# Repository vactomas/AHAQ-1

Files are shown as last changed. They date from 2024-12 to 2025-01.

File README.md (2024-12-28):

# AHAQ-1 -> AstroHex Air Quality v1

AHAQ-1 is an air quality station. Currently, it is an on-going project in development.

This device is based on the ESP32-C6 microcontroller. It features SCD4X CO2 sensor, BMP280 for temperature and ambient pressure measurements and SEN55 for PM1-10, NOx and VOCs. Additionaly, there are two I2C expansion ports for additional sensors. There is also a connector for E-Paper display.

ESPhome is the firmware of choice for AHAQ-1. This allows for easy integration with Home Assistant instances.

This repo contains all the necessary files to build and flash this device.

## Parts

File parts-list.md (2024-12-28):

# Part list

 - Linear regulator - https://www.tme.eu/cz/en/details/tlv75533pdbvr/ldo-unregulated-voltage-regulators/texas-instruments/
 - ESP32-C6-MINI - https://www.tme.eu/cz/en/details/esp32-c6-mini-1-n4/iot-wifi-bluetooth-modules/espressif/
 - SCD41
 - BMP280
 - SEN55 - https://www.tme.eu/cz/en/details/sen55-sdn-t/gas-sensors/sensirion/3-000-593/ - optional
 - E-Paper display - https://www.laskakit.cz/good-display-gdew0213t5d-2-13--250x122-epaper-displej-grayscale/ - optional
 - USB-C connector - https://www.tme.eu/cz/details/usb4105-gf-a/konektory-usb-a-ieee1394/gct/
 - ESD protection - https://www.tme.eu/cz/en/details/usblc6-4sc6y/protection-diodes-arrays/stmicroelectronics/
 - Crystal - https://www.tme.eu/cz/en/details/3cd-32.768kezb-t/smd-quartz-crystals/qst/qt3cd-32-768kezb-t/ - optional
 - FPC connector - https://www.tme.eu/cz/en/details/fh12-24s-0.5sh-55/connectors-ffc-fpc-0-5mm/hirose/fh12-24s-0-5sh-55/

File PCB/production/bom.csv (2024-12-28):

Designator | Footprint | Quantity | Value | LCSC Part #
C1, C12, C13, C2, C25, C26, C28, C29, C3, C30, C8 | 0603 | 11 | 100nF
C10, C11 | 0805 | 2 | 12pF
C14, C21, C22, C24, C6, C7 | 0805 | 6 | 4.7uF
C15, C16, C17, C18, C19, C20, C23, C27, C4, C5, C9 | 0603 | 11 | 1uF
D2, D3, D4 | D_SOD-123 | 3 | MBR0530
J1 | USB_C_Receptacle_GCT_USB4105-xx-A_16P_TopMnt_Horizontal | 1 | USB_C_Receptacle_USB2.0_16P
J2 | JST_SH_BM03B-SRSS-TB_1x03-1MP_P1.00mm_Vertical | 1 | UART
J3 | JST_SH_BM04B-SRSS-TB_1x04-1MP_P1.00mm_Vertical | 1 | I2C_3
J4 | JST_GH_BM06B-GHS-TBT_1x06-1MP_P1.25mm_Vertical | 1 | SEN55
J5 | JST_SH_BM04B-SRSS-TB_1x04-1MP_P1.00mm_Vertical | 1 | I2C_1
J6 | JST_SH_BM04B-SRSS-TB_1x04-1MP_P1.00mm_Vertical | 1 | I2C_2
J9 | Hirose_FH12-24S-0.5SH_1x24-1MP_P0.50mm_Horizontal | 1 | E-Paper
L1 | 0805 | 1 | 68uH
Q1 | SOT-323_SC-70 | 1 | Si1308EDL
R10 | 0402 | 1 | 10M
R11 | 0603 | 1 | 10K
R13 | 0805 | 1 | 0.47R
R14, R15 | 0603 | 2 | 2.2K
R5, R6 | 0603 | 2 | 5.1K
U1 | ESP32-C6-MINI-1 | 1 | ESP32-C6-MINI-1/U
U2 | Sensirion_SCD4x-1EP_10.1x10.1mm_P1.25mm_EP4.8x4.8mm | 1 | SCD41-D-R2
U3 | Bosch_LGA-8_2x2.5mm_P0.65mm_ClockwisePinNumbering | 1 | BMP280
U4, U5, U7 | SOT-23-5 | 3 | TLV75533PDBV
U6 | SOT-666 | 1 | USBLC6-2P6
Y1 | Crystal_SMD_3215-2Pin_3.2x1.5mm | 1 | 32.768kHz

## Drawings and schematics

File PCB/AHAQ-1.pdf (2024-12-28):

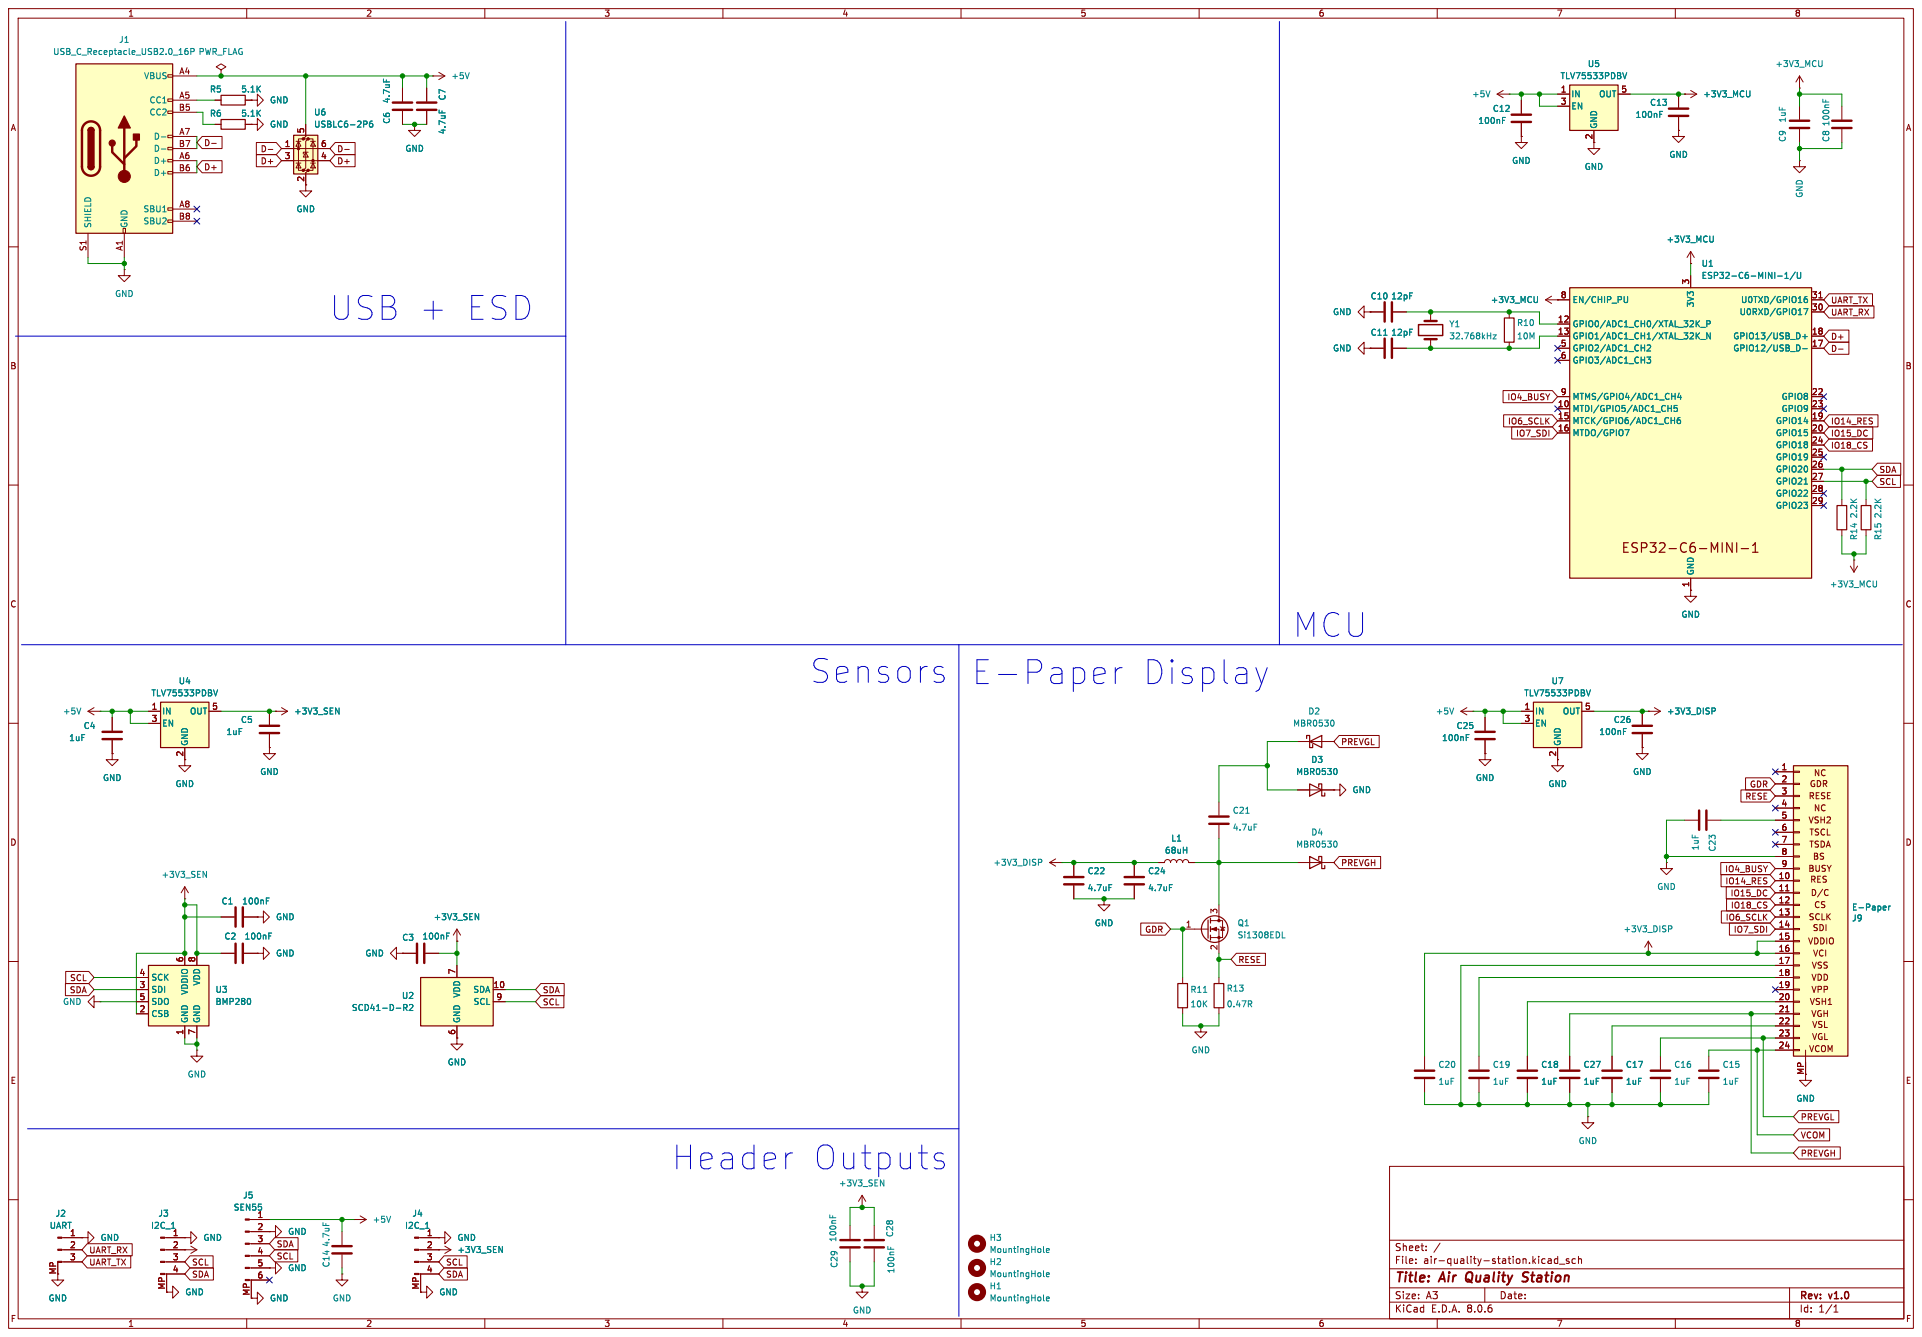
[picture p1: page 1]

1 CSB 2 SDI 3 SCK 4 SDO 5 VDDIO

Id: 1/1 Title: Air Quality Station

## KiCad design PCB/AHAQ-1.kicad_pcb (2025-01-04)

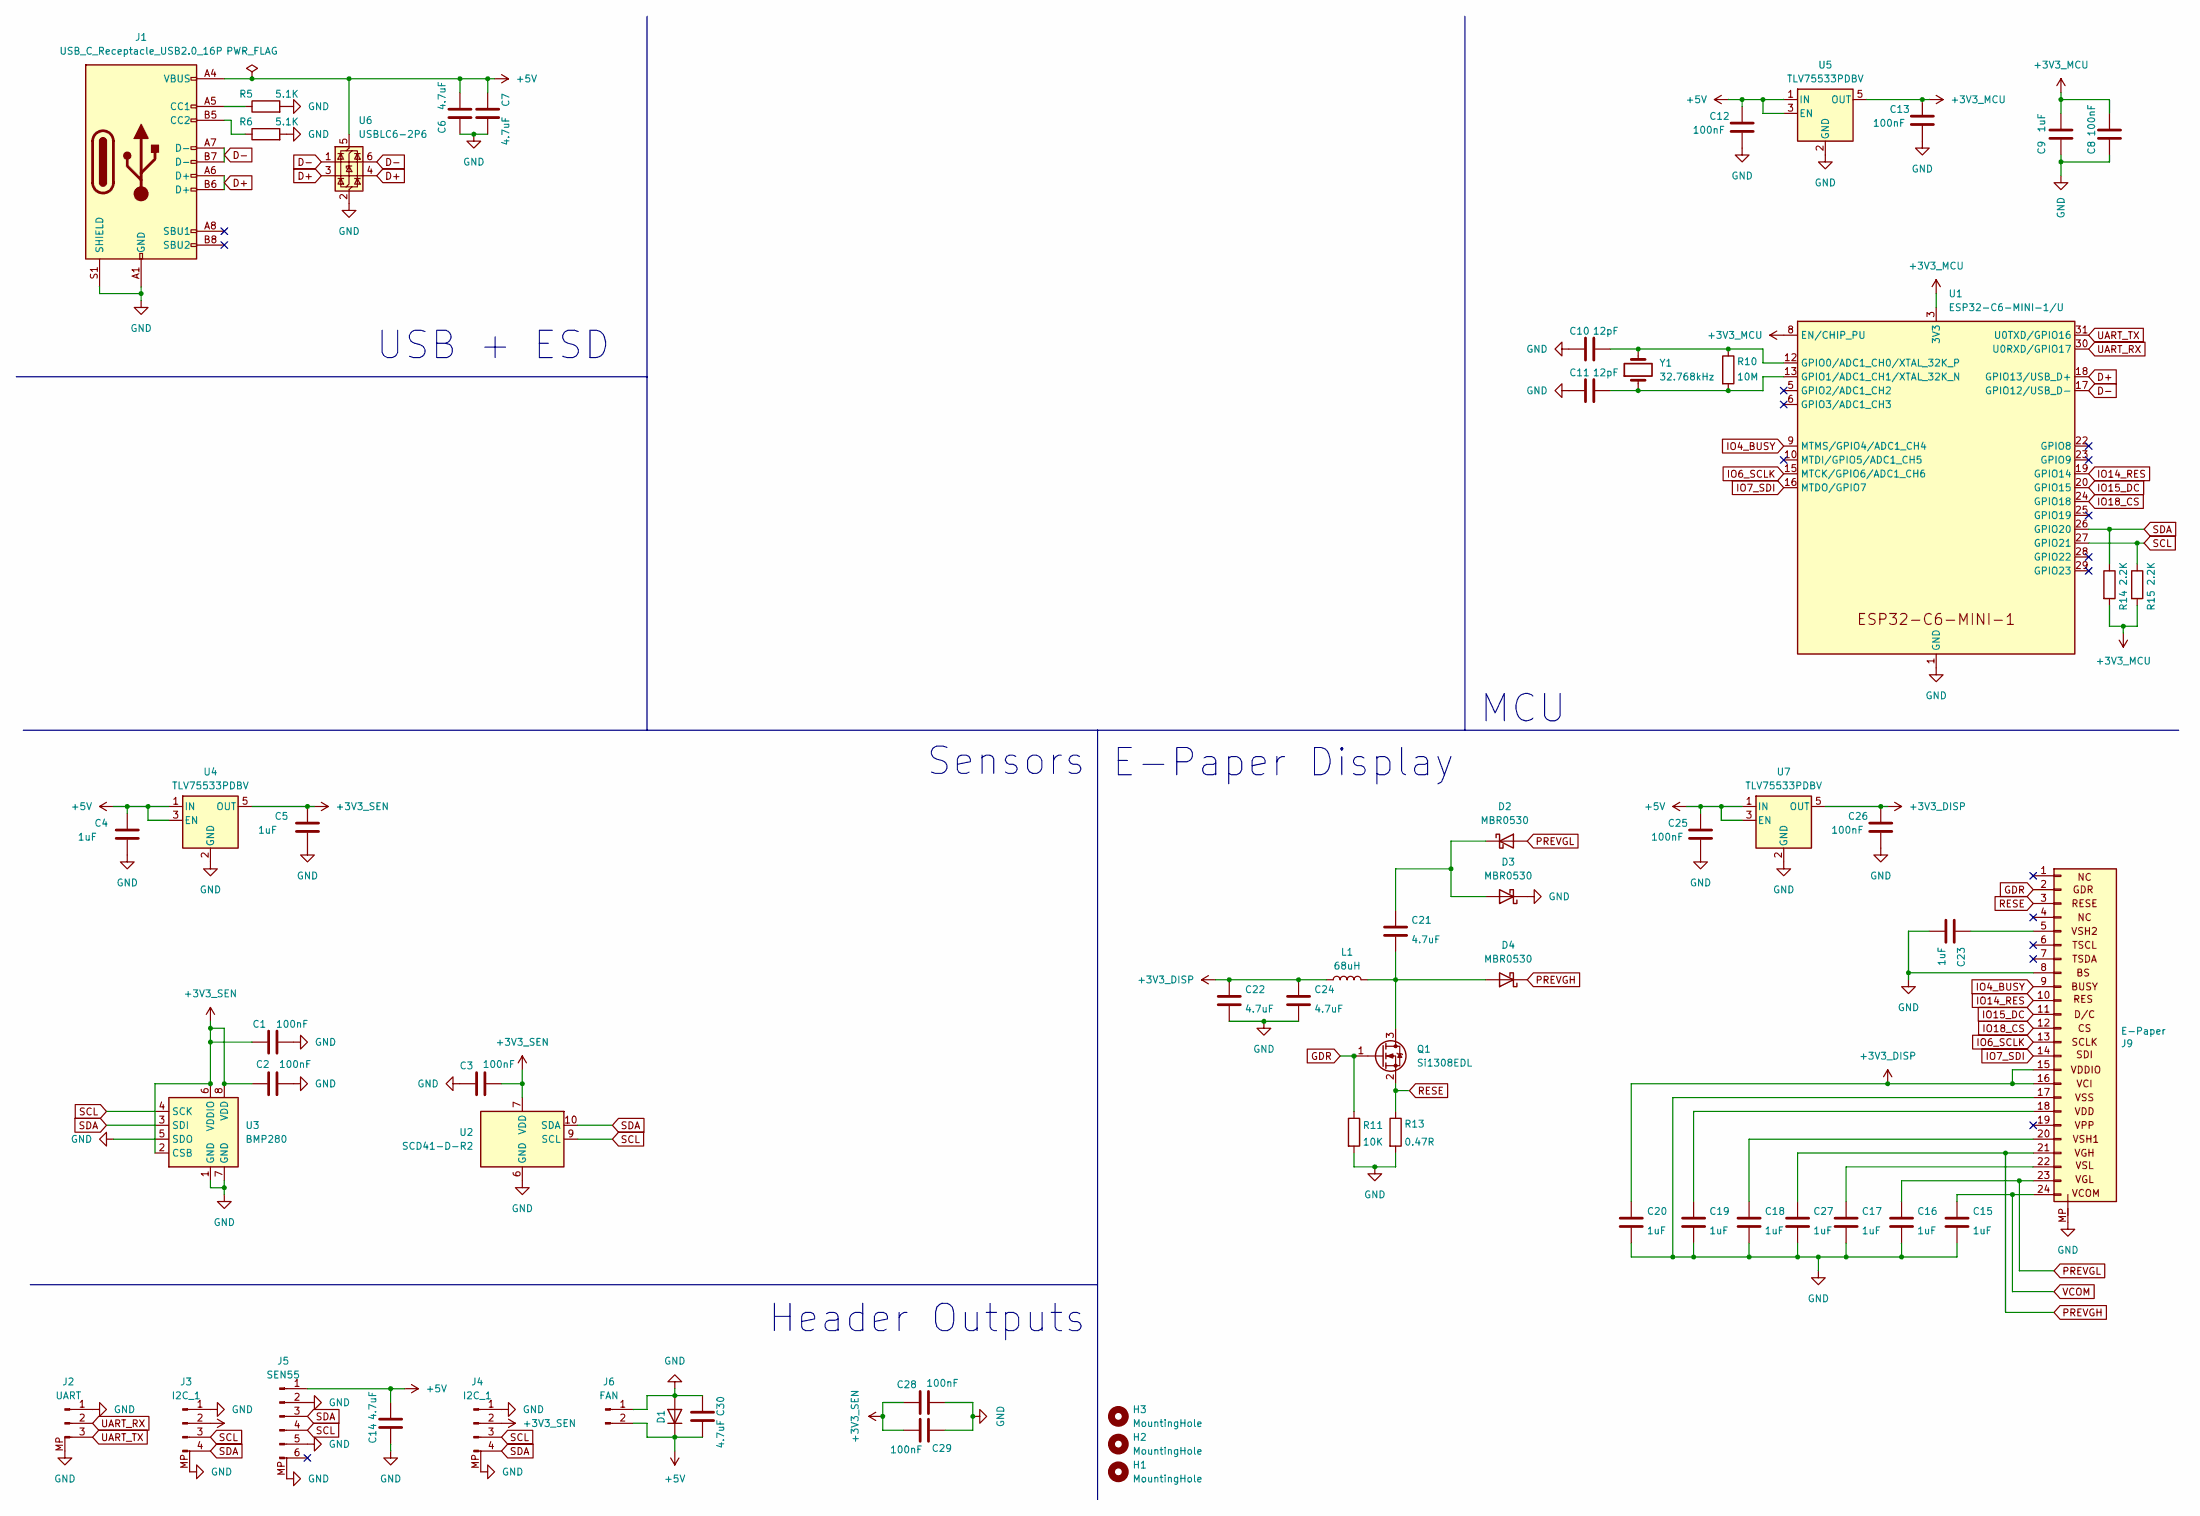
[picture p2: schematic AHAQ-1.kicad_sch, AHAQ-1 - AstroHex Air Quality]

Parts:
C1, C2, C3, C8, C12, C13, C25, C26, C28, C29: 100nF; C_0603_1608Metric
C4, C5, C9, C15, C16, C17, C18, C19, C20, C23, C27: 1uF; C_0603_1608Metric
C6, C7, C14, C21, C22, C24, C30: 4.7uF; C_0805_2012Metric
C10, C11: 12pF; C_0805_2012Metric
D1: D; D_0603_1608Metric
D2, D3, D4: MBR0530; D_SOD-123
H1, H2, H3: MountingHole; MountingHole_2.2mm_M2_ISO7380
J1: USB_C_Receptacle_USB2.0_16P; USB_C_Receptacle_GCT_USB4105-xx-A_16P_TopMnt_Horizontal
J2: UART; JST_SH_SM03B-SRSS-TB_1x03-1MP_P1.00mm_Horizontal
J3, J4: I2C_1; JST_SH_SM04B-SRSS-TB_1x04-1MP_P1.00mm_Horizontal
J5: SEN55; JST_GH_BM06B-GHS-TBT_1x06-1MP_P1.25mm_Vertical
J6: FAN; JST_PH_B2B-PH-K_1x02_P2.00mm_Vertical
J9: E-Paper; Hirose_FH12-24S-0.5SH_1x24-1MP_P0.50mm_Horizontal
L1: 68uH; L_0805_2012Metric
Q1: Si1308EDL; SOT-323_SC-70
R5, R6: 5.1K; R_0603_1608Metric
R10: 10M; R_0402_1005Metric
R11: 10K; R_0603_1608Metric
R13: 0.47R; R_0805_2012Metric
R14, R15: 2.2K; R_0603_1608Metric
U1: ESP32-C6-MINI-1/U; ESP32-C6-MINI-1
U2: SCD41-D-R2; Sensirion_SCD4x-1EP_10.1x10.1mm_P1.25mm_EP4.8x4.8mm
U3: BMP280; Bosch_LGA-8_2x2.5mm_P0.65mm_ClockwisePinNumbering
U4, U5, U7: TLV75533PDBV; SOT-23-5
U6: USBLC6-2P6; SOT-666
Y1: 32.768kHz; Crystal_SMD_3215-2Pin_3.2x1.5mm

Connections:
+3V3_DISP: C20.1, C22.1, C24.1, C26.1, J9.15, J9.16, L1.1, U7.5 (OUT)
+3V3_SEN: C1.2, C2.1, C3.1, C5.1, C28.2, C29.1, J3.2, J4.2, U2.7 (VDD), U2.19 (VDD), U3.2 (CSB), U3.6 (VDDIO), U3.8 (VDD), U4.5 (OUT)
D+: J1.A6 (D+), J1.B6 (D+), U1.18 (GPIO13/USB_D+), U6.3 (I/O2), U6.4 (I/O2)
D-: J1.A7 (D-), J1.B7 (D-), U1.17 (GPIO12/USB_D-), U6.1 (I/O1), U6.6 (I/O1)
GDR: J9.2, Q1.1 (G), R11.1
GND: C1.1, C2.2, C3.2, C4.2, C5.2, C6.2, C7.1, C8.2, C9.2, C10.2, C11.2, C12.2, C13.2, C14.2, C15.2, C16.2, C17.2, C18.2, C19.2, C20.2, C22.2, C23.2, C24.2, C25.2, C26.2, C27.2, C28.1, C29.2, C30.2, D1.2 (A), D3.1 (K), J1.A1 (GND), J1.A12 (GND), J1.B1 (GND), J1.B12 (GND), J1.S1 (SHIELD), J2.1, J2.MP, J3.1, J3.MP, J4.1, J4.MP, J5.2, J5.5, J5.MP, J6.1, J9.8, J9.17, J9.MP, R5.2, R6.2, R11.2, R13.2, U1.1 (GND), U1.2 (GND), U1.11 (GND), U1.14 (GND), U1.36 (GND), U1.37 (GND), U1.38 (GND), U1.39 (GND), U1.40 (GND), U1.41 (GND), U1.42 (GND), U1.43 (GND), U1.44 (GND), U1.45 (GND), U1.46 (GND), U1.47 (GND), U1.48 (GND), U1.49 (GND), U1.50 (GND), U1.51 (GND), U1.52 (GND), U1.53 (GND), U2.6 (GND), U2.20 (GND), U2.21 (GND), U3.1 (GND), U3.5 (SDO), U3.7 (GND), U4.2 (GND), U5.2 (GND), U6.2 (GND), U7.2 (GND)
IO4_BUSY: J9.9, U1.9 (MTMS/GPIO4/ADC1_CH4)
IO6_SCLK: J9.13, U1.15 (MTCK/GPIO6/ADC1_CH6)
IO7_SDI: J9.14, U1.16 (MTDO/GPIO7)
IO14_RES: J9.10, U1.19 (GPIO14)
IO15_DC: J9.11, U1.20 (GPIO15)
IO18_CS: J9.12, U1.24 (GPIO18)
unnamed: C21.1, D2.1 (K), D3.2 (A)
unnamed: C21.2, D4.2 (A), L1.2, Q1.3 (D)
unnamed: J1.A5 (CC1), R5.1
unnamed: J1.B5 (CC2), R6.1
unnamed: C23.1, J9.5
unnamed: C19.1, J9.18
unnamed: C18.1, J9.20
unnamed: C17.1, J9.22
unnamed: C10.1, R10.1, U1.12 (GPIO0/ADC1_CH0/XTAL_32K_P), Y1.2
unnamed: C11.1, R10.2, U1.13 (GPIO1/ADC1_CH1/XTAL_32K_N), Y1.1
PREVGH: C27.1, D4.1 (K), J9.21
PREVGL: C16.1, D2.2 (A), J9.23
RESE: J9.3, Q1.2 (S), R13.1
SCL: J3.3, J4.3, J5.4, R15.1, U1.27 (GPIO21), U2.9 (SCL), U3.4 (SCK)
SDA: J3.4, J4.4, J5.3, R14.1, U1.26 (GPIO20), U2.10 (SDA), U3.3 (SDI)
UART_RX: J2.2, U1.30 (U0RXD/GPIO17)
UART_TX: J2.3, U1.31 (U0TXD/GPIO16)
VCOM: C15.1, J9.24

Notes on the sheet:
Header Outputs
USB + ESD
E-Paper Display
Sensors
MCU

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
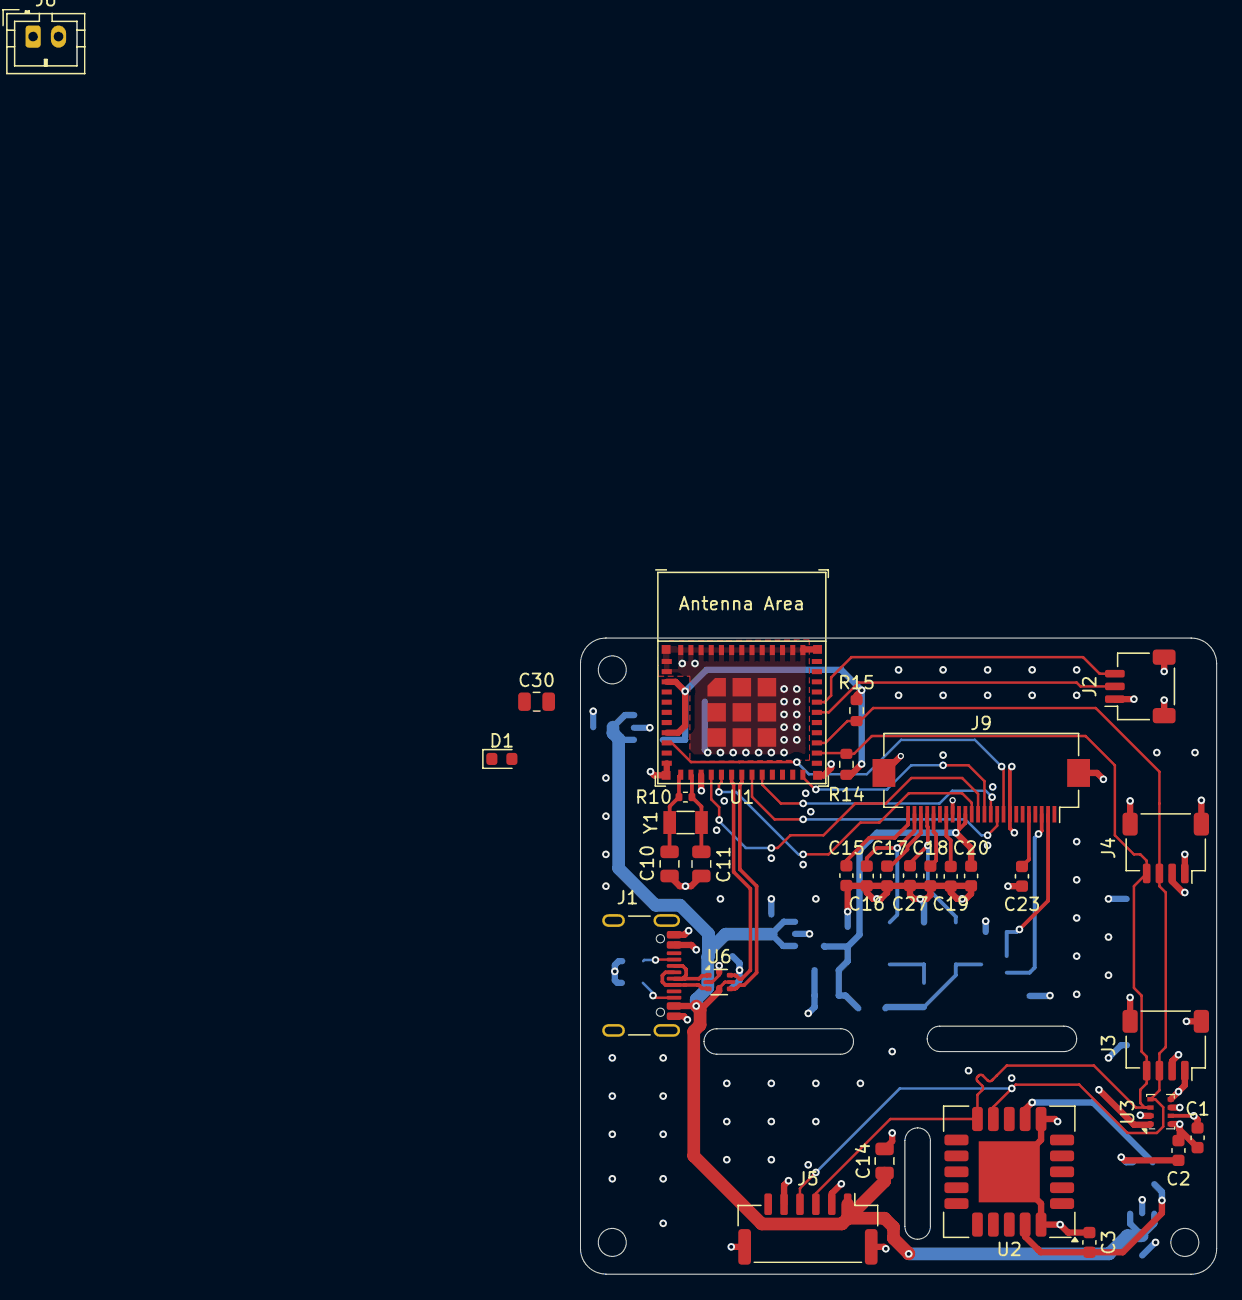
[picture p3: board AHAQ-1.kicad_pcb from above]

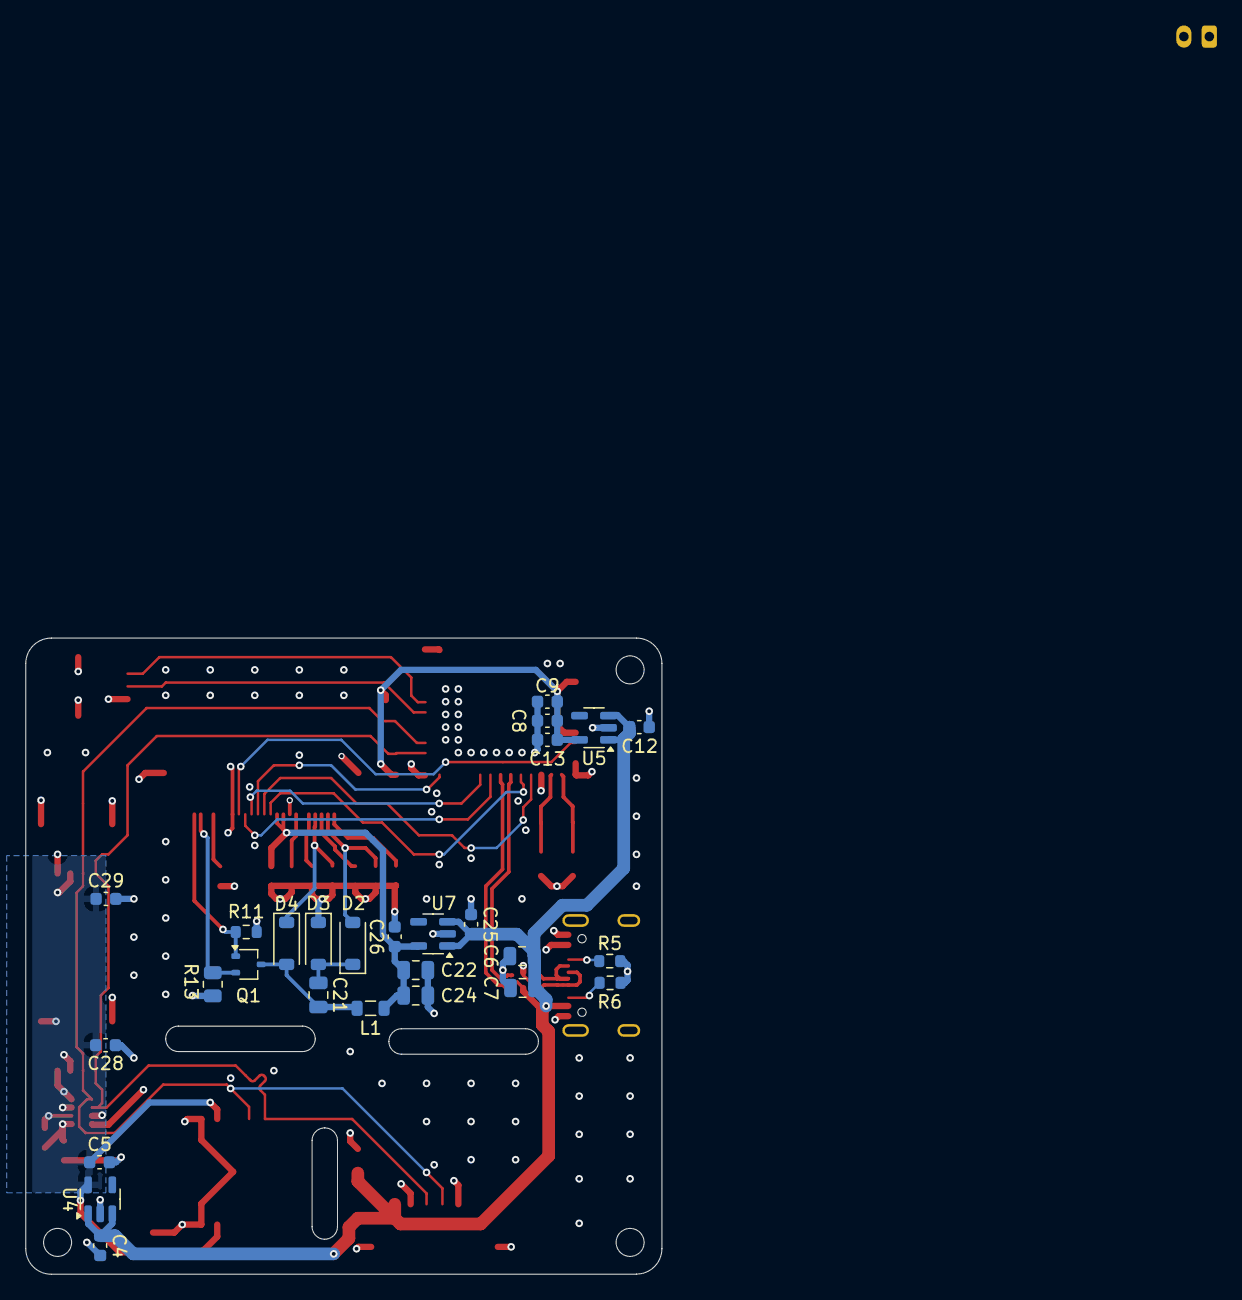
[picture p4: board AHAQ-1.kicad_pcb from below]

Board: 4 copper layers, 50.0 x 50.0 mm, 61 parts (27 on the bottom side), 32 nets.

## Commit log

2024-12-16 Add ESD component
    [air-quality-station.kicad_pcb, air-quality-station.kicad_sch]
2024-12-17 Add E-Paper and Headers to schematic
    [air-quality-station.kicad_pcb, air-quality-station.kicad_sch]
2024-12-17 ERC check and fixes
    [air-quality-station.kicad_pcb, air-quality-station.kicad_sch]
2024-12-18 First PCB layout, added mounting holes and PCB footprint
    [air-quality-station.kicad_pcb, air-quality-station.kicad_sch]
2024-12-26 Updated schematic, finished PCB layout and routing
    [air-quality-station.kicad_pcb, air-quality-station.kicad_sch]
2024-12-26 Update PDF schematic
2024-12-27 Drop battery support, add stitching vias and decooupling capacitors
    [air-quality-station.kicad_pcb, air-quality-station.kicad_sch, bom.csv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]
2024-12-28 Improved LDOs, dropped one extension port
    [air-quality-station.kicad_pcb, air-quality-station.kicad_sch, bom.csv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]
2024-12-28 Rename to AHQA-1, README
    [AHAQ-1.kicad_pcb, AHAQ-1.kicad_sch]
2025-01-04 Added FAN output
    [AHAQ-1.kicad_pcb, AHAQ-1.kicad_sch]
